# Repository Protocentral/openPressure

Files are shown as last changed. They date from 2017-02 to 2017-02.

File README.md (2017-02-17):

# Protocentral OpenPressure

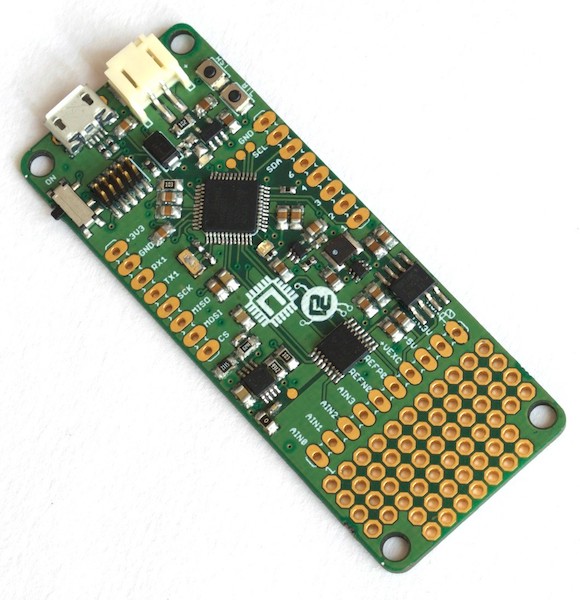
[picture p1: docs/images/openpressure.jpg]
OpenPressure


OpenPressure is a result of our work in trying to interface pressure sensors to an ADC as well as a display system based on Arduino. We found the ADS1220 to be a great chip that can directly take a 4-wire, 3-wire or a 2-wire sensor and give the digital output. 

Combine this powerful functionality with an ATSAMD21 micro-controller and you've got your very own Arduino-compatible pressure and temperature sensor interface system.

Features
--------
* TI ADS1220 24-bit ADC
* 4-wire sensor can be interfaced directly to the inputs
* On-board 5V band-gap voltage reference
* ATSAMD21 microcontroller loaded with Arduino M0/Zero bootloader
* Programmable with the Arduino IDE
* USB CDC Interface for data transfer
* "Cap" compatibility to add Bluetooth/WiFi/SD Card interfaces
* On-board 3.7V Li-Poly battery with charger
* On-board Boost DC/DC converter 

Repository Contents
-------------------
* **/hardware** - All Eagle design files (.brd, .sch)
* **/software** - Arduino libraries and example code
* **/docs** - Additional Documentation

Board Overview
--------------
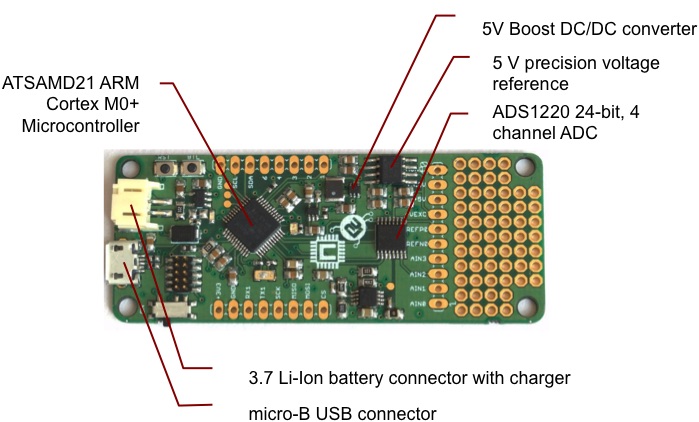
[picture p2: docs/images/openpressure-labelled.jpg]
labelled


How to setup Arduino support for openPressure
---------------------------------------------------
OpenPressure is powered by the Arduino Zero board support file.The first thing you will need to do is to download the latest release of the Arduino IDE. You will need to be using version 1.6.4 or higher. 

If you want to program your Zero while offline you need to install the Arduino Desktop IDE and add the Atmel SAMD Core to it. This simple procedure is done selecting Tools menu, then Boards and last Boards Manager, as documented in the Arduino Boards Manager page. 

* Select Tools > Board > Board Manager
* You should find Arduino SAMD(32-bit ARM cortex-M0+) boards listed in the Board Manager window.

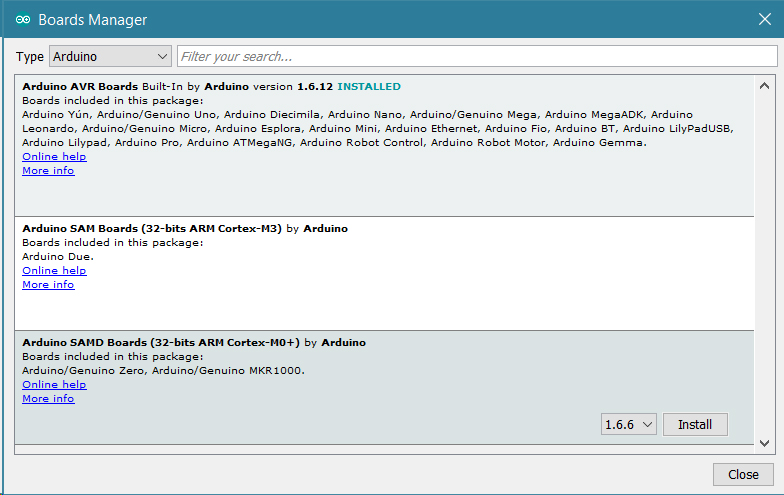
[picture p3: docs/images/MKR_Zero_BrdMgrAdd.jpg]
board_manager
 
 
* Click the “Install” button on the chosen category.The download process will begin and install the toolchain for SAMD microcontrollers.
* Restart Arduino and look under Tools > Boards and you should see the addition of the Arduino boards in your board list.
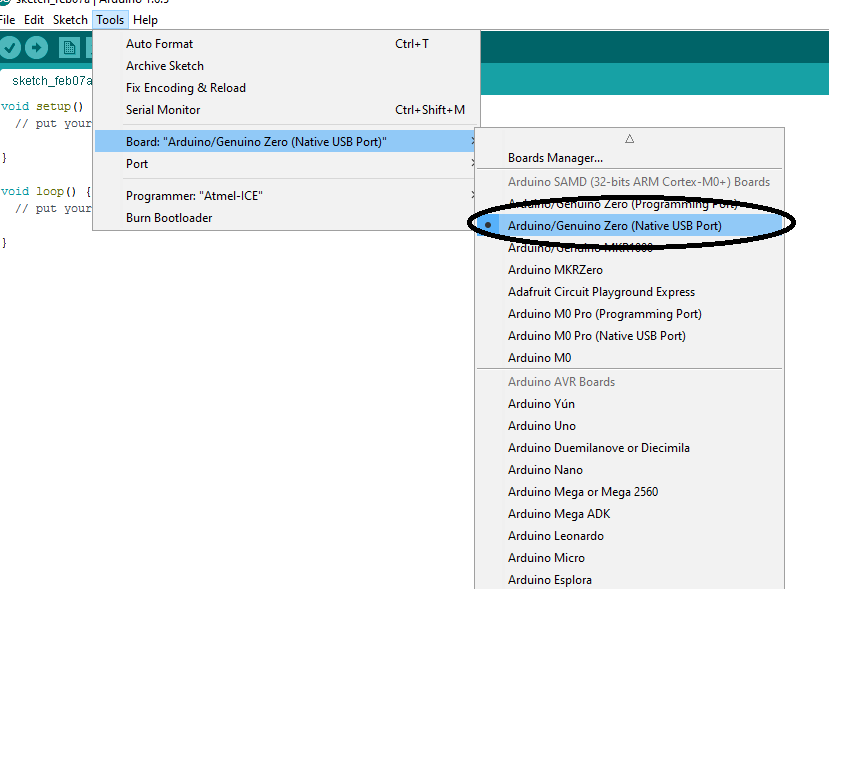
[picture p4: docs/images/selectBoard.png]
board


Setup Arduino Sketch
--------------------
We have provided a few Arduino sketch examples . They are designed to work right away with no changes. To make the examples work with your board, you simply need to upload the code to your board.

License Information
-------------------
This product is open source!

Please use, reuse, and modify these files as you see fit. Please maintain attribution to Protocentral and release anything derivative under the same license.

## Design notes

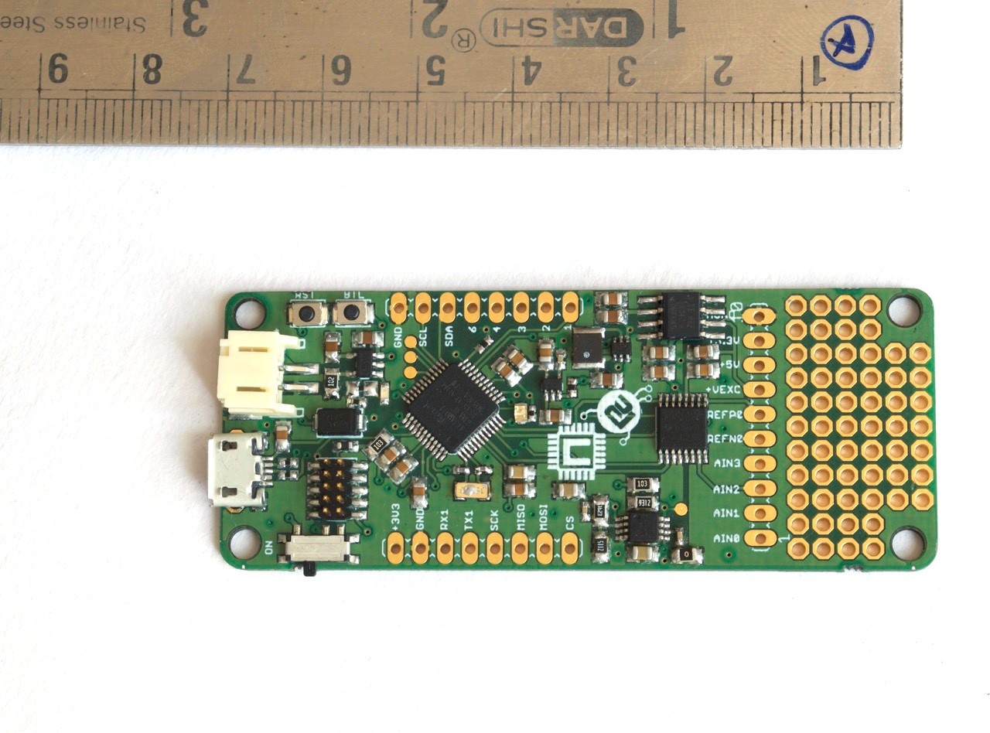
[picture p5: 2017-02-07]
docs/images/boardSize.jpg

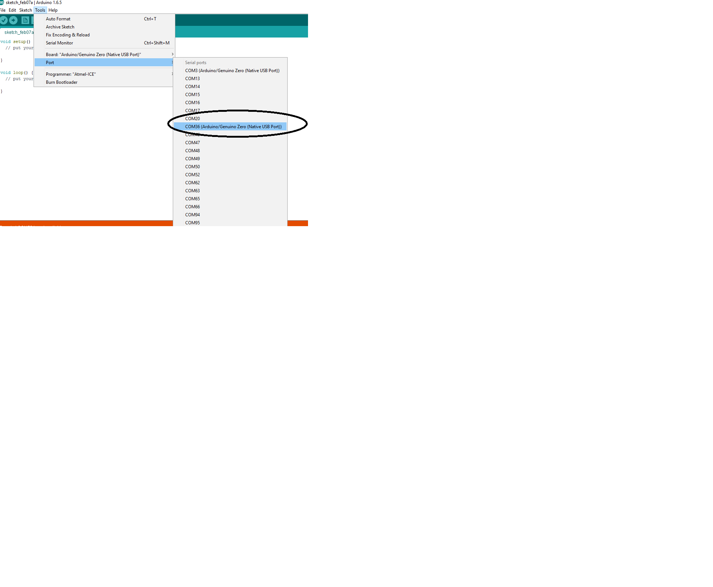
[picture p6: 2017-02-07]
docs/images/port.png

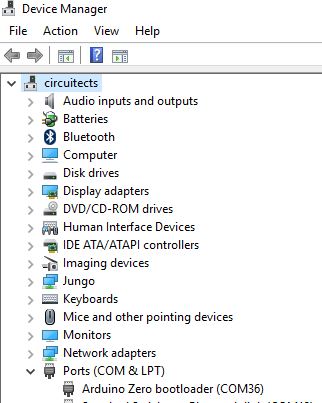
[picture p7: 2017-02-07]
docs/images/deviceManager.JPG

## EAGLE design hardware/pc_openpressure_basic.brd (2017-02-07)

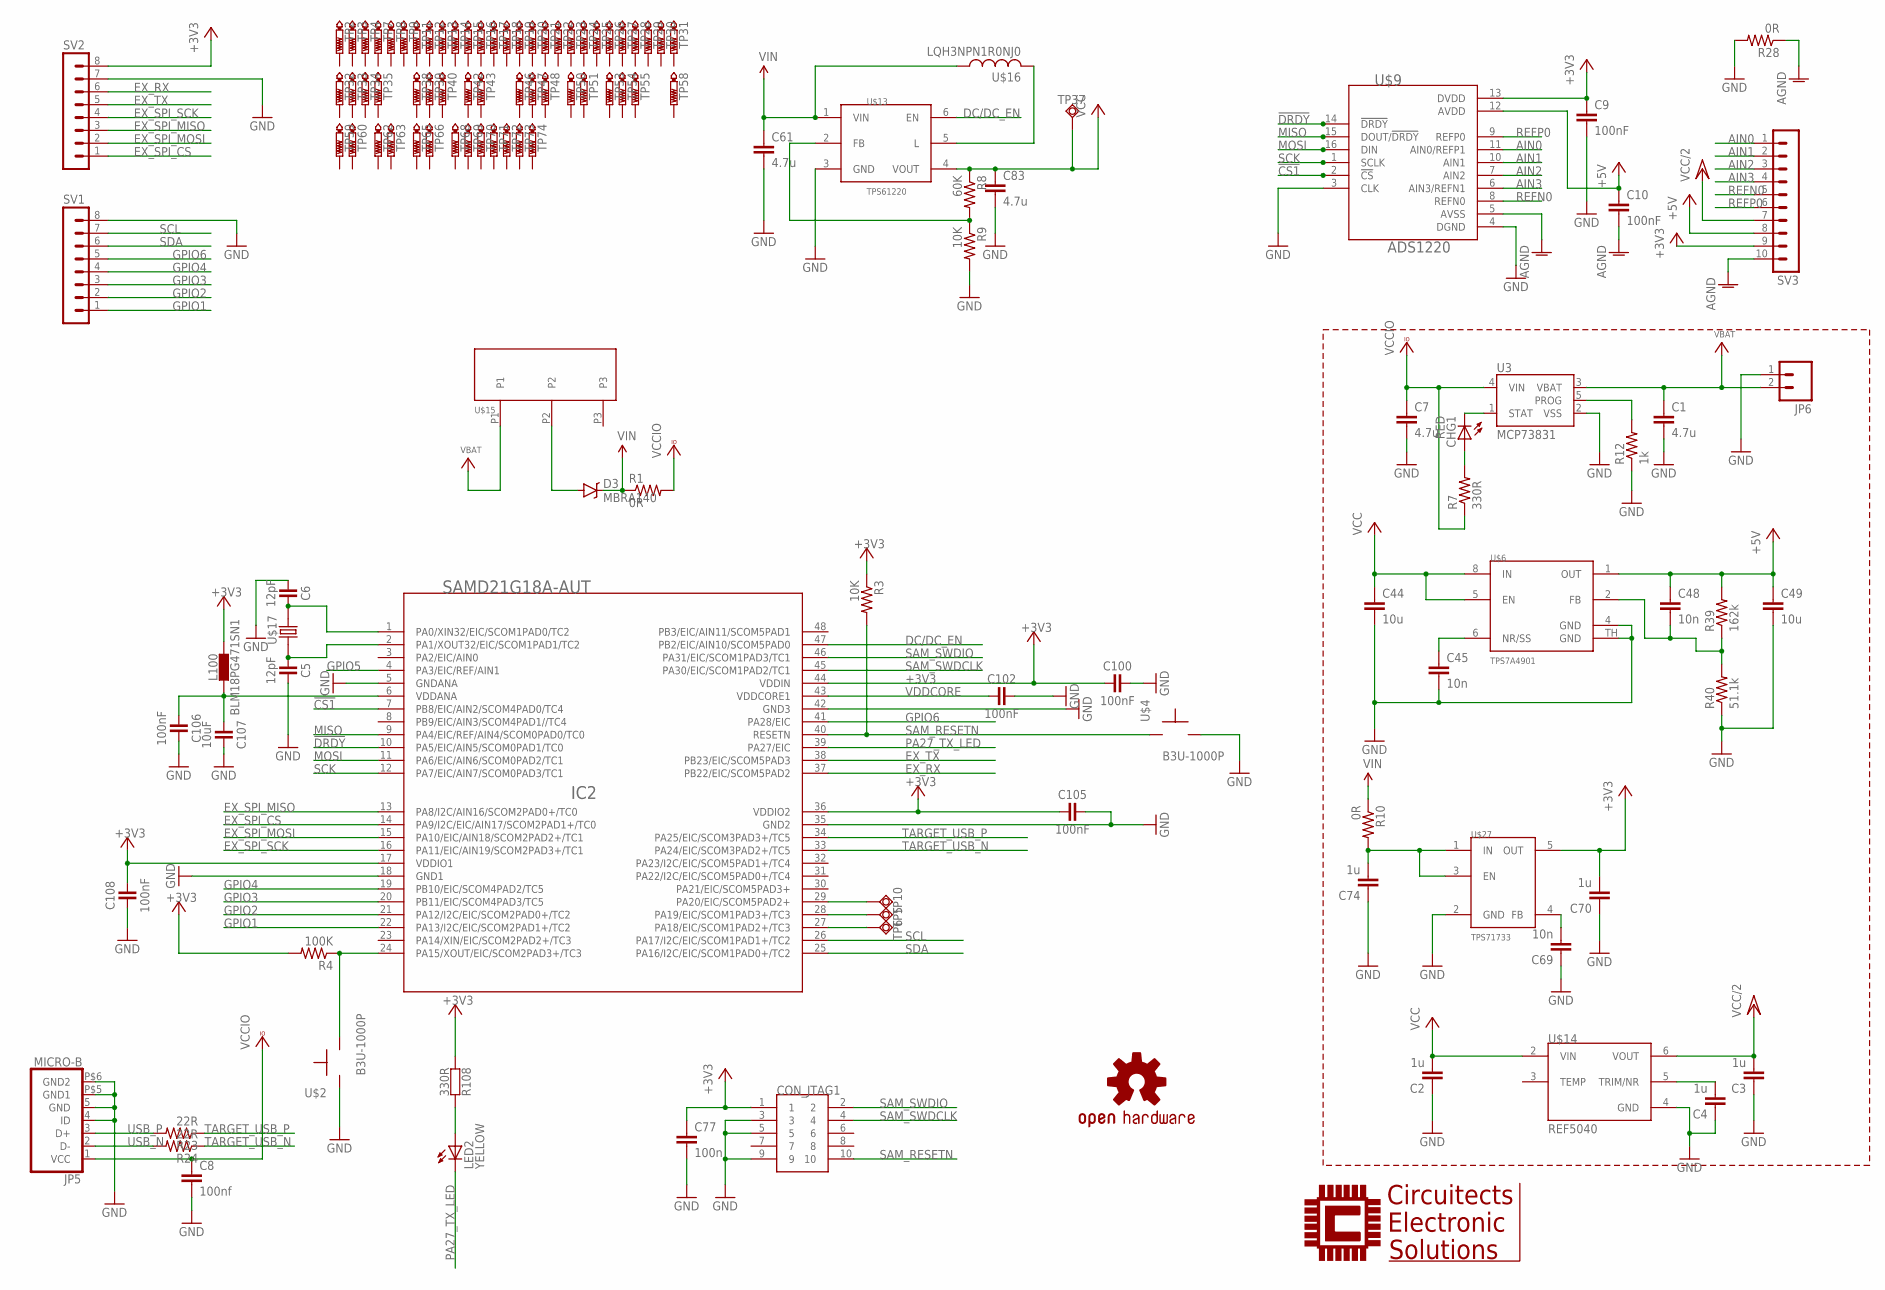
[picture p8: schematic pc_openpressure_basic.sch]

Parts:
C1, C7, C61, C83: 4.7u; C0805
C2, C3, C4, C70, C74: 1u; C0805
C5, C6: 12pF; C0402
C8: 100nf; C0805
C9, C10, C100, C102, C105, C106, C108: 100nF; C0805
C44, C49: 10u; C0805
C45, C48, C69: 10n; C0402
C77: 100n; C0805
C107: 10uF; C0805
CHG1: RED; CHIPLED_0603
CON_JTAG1: HDR-SMT-50MIL/5X2
D3: MBRA140; SMA-DIODE
IC2: SAMD21G18A-AUT; TQFP48
JP5: MICRO-B
JP6: M02-JST-2MM-SMT; JST-2-SMD
L100: BLM18PG471SN1; C0603
LED2: YELLOW; CHIPLED_0603
R1, R10: 0R; R0402
R3, R9: 10K; R0805
R4: 100K; R0402
R7: 330R; R0805
R8: 60K; R0805
R12: 1k; R0805
R23, R24: 22R; R0402
R28: 0R; R0805
R39: 162k; R0805
R40: 51.1k; R0805
R108: 330R; C0402
SV1, SV2: MA08-1
SV3: MA10-1
TP2, TP3, TP4, TP7, TP8, TP9, TP11, TP12, TP13, TP14, TP15, TP16, TP17, TP18, TP19, TP20, TP21, TP22, TP23, TP24, TP25, TP26, TP27, TP28, TP29, TP30, TP31, TP32, TP33, TP34, TP35, TP38, TP39, TP40, TP42, TP43, TP46, TP47, TP48, TP50, TP51, TP53, TP54, TP55, TP58, TP59, TP60, TP62, TP63, TP65, TP66, TP68, TP69, TP70, TP71, TP72, TP73, TP74: PTR1PAD1-13; P1-13
TP5, TP6, TP10, TP37: TPSQB1,27; B1,27
U3: MCP73831; SOT23-5
U$2, U$4: B3U-1000P
U$6: TPS7A4901; S-PDSO-G08
U$7: CES-LOGO; CES-LOGO-SMALL
U$8: PROTY-LOGO; LOGO-PROTY
U$9: ADS1220; TSSOP-16
U$13: TPS61220; SC-70-6
U$14: REF5040; SO-08M
U$15: PCM12SMTR
U$16: LQH3NPN1R0NJ0; LQH3NP
U$17: ECS-X-34B; ECX-31B
U$18: PROTY_LOGO_WITH_TEXT; PROTY_WITH_TEXT
U$19: OSHW-LOGOM; OSHW-LOGO-M
U$27: TPS71733; SC70-5

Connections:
!CS1: IC2.7 (PB8/EIC/AIN2/SCOM4PAD0/TC4), U$9.2 (!CS)
!DRDY: IC2.10 (PA5/EIC/AIN5/SCOM0PAD1/TC0), U$9.14 (!DRDY)
+3V3: C9.1, C70.2, C77.1, C100.1, C105.1, C108.2, CON_JTAG1.1, IC2.17 (VDDIO1), IC2.36 (VDDIO2), IC2.44 (VDDIN), L100.2, R3.1, R4.2, R108.1, SV2.8, SV3.9, U$9.13 (DVDD), U$27.5 (OUT)
+5V: C10.1, C48.1, C49.1, R39.2, SV3.8, U$6.1 (OUT), U$9.12 (AVDD)
AGND: C10.2, R28.1, SV3.10, U$9.5 (AVSS)
AIN0: SV3.1, U$9.11 (AIN0/REFP1)
AIN1: SV3.2, U$9.10 (AIN1)
AIN2: SV3.3, U$9.7 (AIN2)
AIN3: SV3.4, U$9.6 (AIN3/REFN1)
DC/DC_EN: IC2.47 (PB2/EIC/AIN10/SCOM5PAD0), U$13.6 (EN)
EX_RX: IC2.37 (PB22/EIC/SCOM5PAD2), SV2.6
EX_SPI_CS: IC2.14 (PA9/I2C/EIC/AIN17/SCOM2PAD1+/TC0), SV2.1
EX_SPI_MISO: IC2.13 (PA8/I2C/AIN16/SCOM2PAD0+/TC0), SV2.3
EX_SPI_MOSI: IC2.15 (PA10/EIC/AIN18/SCOM2PAD2+/TC1), SV2.2
EX_SPI_SCK: IC2.16 (PA11/EIC/AIN19/SCOM2PAD3+/TC1), SV2.4
EX_TX: IC2.38 (PB23/EIC/SCOM5PAD3), SV2.5
GND: C1.2, C2.1, C3.1, C4.1, C5.2, C6.1, C7.2, C8.2, C9.2, C44.2, C45.2, C49.2, C61.2, C69.1, C70.1, C74.1, C77.2, C83.2, C100.2, C102.2, C105.2, C106.2, C107.2, C108.1, CON_JTAG1.3, CON_JTAG1.5, CON_JTAG1.9, IC2.5 (GNDANA), IC2.18 (GND1), IC2.35 (GND2), IC2.42 (GND3), JP5.4 (ID), JP5.5 (GND), JP5.P$5 (GND1), JP5.P$6 (GND2), JP6.1, R9.2, R12.1, R28.2, R40.1, SV1.8, SV2.7, U3.2 (VSS), U$2.P$1, U$4.P$2, U$6.4 (GND), U$6.TH (GND), U$9.3 (CLK), U$9.4 (DGND), U$13.3 (GND), U$14.4 (GND), U$27.2 (GND)
GPIO1: IC2.22 (PA13/I2C/EIC/SCOM2PAD1+/TC2), SV1.1
GPIO2: IC2.21 (PA12/I2C/EIC/SCOM2PAD0+/TC2), SV1.2
GPIO3: IC2.20 (PB11/EIC/SCOM4PAD3/TC5), SV1.3
GPIO4: IC2.19 (PB10/EIC/SCOM4PAD2/TC5), SV1.4
GPIO5: IC2.4 (PA3/EIC/REF/AIN1)
GPIO6: IC2.41 (PA28/EIC), SV1.5
MISO: IC2.9 (PA4/EIC/REF/AIN4/SCOM0PAD0/TC0), U$9.15 (DOUT/!DRDY)
MOSI: IC2.11 (PA6/EIC/AIN6/SCOM0PAD2/TC1), U$9.16 (DIN)
unnamed: C6.2, IC2.1 (PA0/XIN32/EIC/SCOM1PAD0/TC2), U$17.P$2 (2)
unnamed: C74.2, R10.2, U$27.1 (IN), U$27.3 (EN)
unnamed: D3.A, U$15.P2
unnamed: R8.2, R9.1, U$13.2 (FB)
unnamed: IC2.24 (PA15/XOUT/EIC/SCOM2PAD3+/TC3), R4.1, U$2.P$2
unnamed: C5.1, IC2.2 (PA1/XOUT32/EIC/SCOM1PAD1/TC2), U$17.P$1 (1)
unnamed: C106.1, C107.1, IC2.6 (VDDANA), L100.1
unnamed: IC2.27 (PA18/EIC/SCOM1PAD2+/TC3), TP6.TP
unnamed: CHG1.C, U3.1 (STAT)
unnamed: CHG1.A, R7.2
unnamed: C45.1, U$6.6 (NR/SS)
unnamed: IC2.28 (PA19/EIC/SCOM1PAD3+/TC3), TP5.TP
unnamed: IC2.29 (PA20/EIC/SCOM5PAD2+), TP10.TP
unnamed: R12.2, U3.5 (PROG)
unnamed: LED2.A, R108.2
unnamed: C48.2, R39.1, R40.2, U$6.2 (FB)
unnamed: C4.2, U$14.5 (TRIM/NR)
unnamed: U$13.5 (L), U$16.P$2 (2)
unnamed: C69.2, U$27.4 (FB)
PA27_TX_LED: IC2.39 (PA27/EIC), LED2.C
REFN0: SV3.5, U$9.8 (REFN0)
REFP0: SV3.6, U$9.9 (REFP0)
SAM_RESETN: CON_JTAG1.10, IC2.40 (RESETN), R3.2, U$4.P$1
SAM_SWDCLK: CON_JTAG1.4, IC2.45 (PA30/EIC/SCOM1PAD2/TC1)
SAM_SWDIO: CON_JTAG1.2, IC2.46 (PA31/EIC/SCOM1PAD3/TC1)
SCK: IC2.12 (PA7/EIC/AIN7/SCOM0PAD3/TC1), U$9.1 (SCLK)
SCL: IC2.26 (PA17/I2C/EIC/SCOM1PAD1+/TC2), SV1.7
SDA: IC2.25 (PA16/I2C/EIC/SCOM1PAD0+/TC2), SV1.6
TARGET_USB_N: IC2.33 (PA24/EIC/SCOM3PAD2+/TC5), R24.1
TARGET_USB_P: IC2.34 (PA25/EIC/SCOM3PAD3+/TC5), R23.1
USB_N: JP5.2 (D-), R24.2
USB_P: JP5.3 (D+), R23.2
VBAT: C1.1, JP6.2, U3.3 (VBAT), U$15.P1
VCC: C2.2, C44.1, C83.1, R8.1, TP37.TP, U$6.5 (EN), U$6.8 (IN), U$13.4 (VOUT), U$14.2 (VIN)
VCC/2: C3.2, SV3.7, U$14.6 (VOUT)
VCCIO: C7.1, C8.1, JP5.1 (VCC), R1.2, R7.1, U3.4 (VIN)
VDDCORE: C102.1, IC2.43 (VDDCORE1)
VIN: C61.1, D3.C, R1.1, R10.1, U$13.1 (VIN), U$16.P$1 (1)

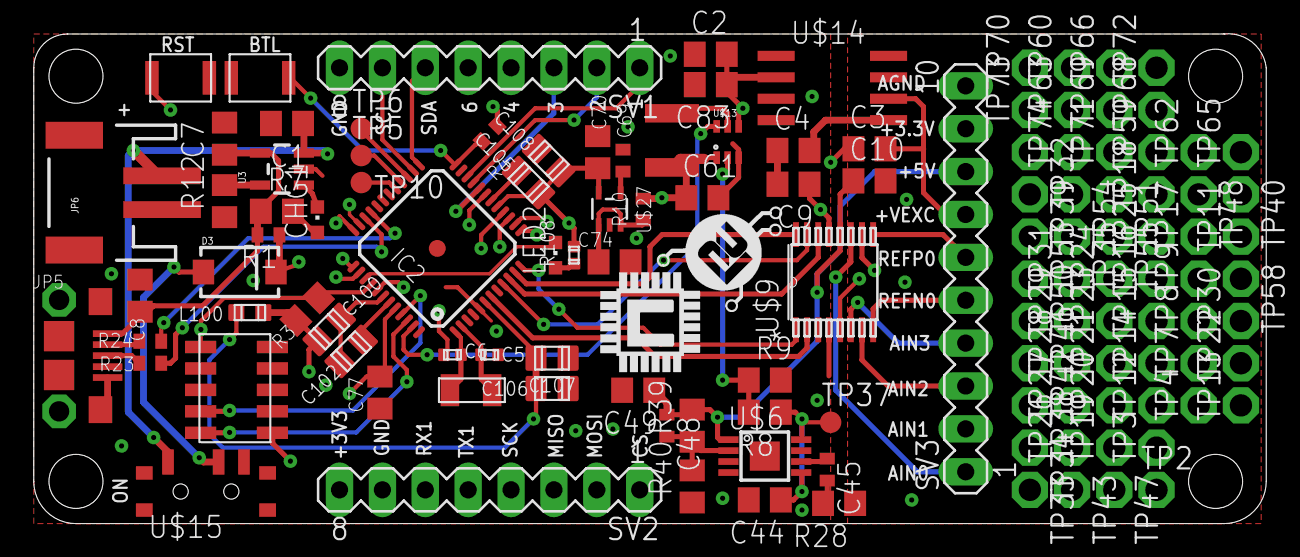
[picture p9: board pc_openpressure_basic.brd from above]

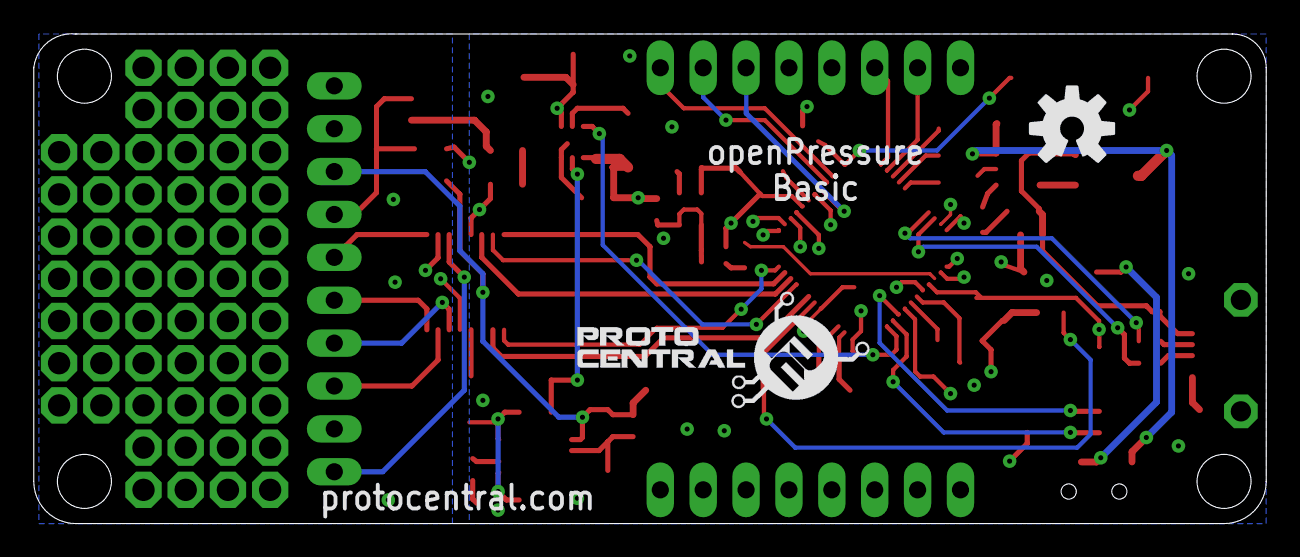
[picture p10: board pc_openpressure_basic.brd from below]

Board: 4 copper layers, 73.0 x 29.0 mm, 128 parts (2 on the bottom side), 62 nets.

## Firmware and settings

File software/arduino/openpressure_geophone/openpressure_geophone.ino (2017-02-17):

 /* +------------+------------------+--------+-----------------+--------------------------------------------------------------------------------------------------------
 * + Pin number +  ZERO Board pin  |  PIN   | Label/Name      | Comments (* is for default peripheral in use)
 * +------------+------------------+--------+-----------------+--------------------------------------------------------------------------------------------------------
 * |            | Digital Low      |        |                 |
 * +------------+------------------+--------+-----------------+--------------------------------------------------------------------------------------------------------
 * | 0          | 0 -> RX          |  PA11  |                 | EIC/EXTINT[11] ADC/AIN[19]           PTC/X[3] *SERCOM0/PAD[3]  SERCOM2/PAD[3]  TCC0/WO[3]  TCC1/WO[1]
 * | 1          | 1 <- TX          |  PA10  |                 | EIC/EXTINT[10] ADC/AIN[18]           PTC/X[2] *SERCOM0/PAD[2]                  TCC0/WO[2]  TCC1/WO[0]
 * | 2          | 2                |  PA14  |                 | EIC/EXTINT[14]                                 SERCOM2/PAD[2]  SERCOM4/PAD[2]  TC3/WO[0]   TCC0/WO[4]
 * | 3          | ~3               |  PA09  |                 | EIC/EXTINT[9]  ADC/AIN[17]           PTC/X[1]  SERCOM0/PAD[1]  SERCOM2/PAD[1] *TCC0/WO[1]  TCC1/WO[3]
 * | 4          | ~4               |  PA08  |                 | EIC/NMI        ADC/AIN[16]           PTC/X[0]  SERCOM0/PAD[0]  SERCOM2/PAD[0] *TCC0/WO[0]  TCC1/WO[2]
 * | 5          | ~5               |  PA15  |                 | EIC/EXTINT[15]                                 SERCOM2/PAD[3]  SERCOM4/PAD[3] *TC3/WO[1]   TCC0/WO[5]
 * | 6          | ~6               |  PA20  |                 | EIC/EXTINT[4]                        PTC/X[8]  SERCOM5/PAD[2]  SERCOM3/PAD[2]             *TCC0/WO[6]
 * | 7          | 7                |  PA21  |                 | EIC/EXTINT[5]                        PTC/X[9]  SERCOM5/PAD[3]  SERCOM3/PAD[3]              TCC0/WO[7]
 * +------------+------------------+--------+-----------------+--------------------------------------------------------------------------------------------------------
 * |            | Digital High     |        |                 |
 * +------------+------------------+--------+-----------------+--------------------------------------------------------------------------------------------------------
 * | 8          | ~8               |  PA06  |                 | EIC/EXTINT[6]  ADC/AIN[6]  AC/AIN[2] PTC/Y[4]  SERCOM0/PAD[2]                 *TCC1/WO[0]
 * | 9          | ~9               |  PA07  |                 | EIC/EXTINT[7]  ADC/AIN[7]  AC/AIN[3] PTC/Y[5]  SERCOM0/PAD[3]                 *TCC1/WO[1]
 * | 10         | ~10              |  PA18  |                 | EIC/EXTINT[2]                        PTC/X[6] +SERCOM1/PAD[2]  SERCOM3/PAD[2] *TC3/WO[0]    TCC0/WO[2]
 * | 11         | ~11              |  PA16  |                 | EIC/EXTINT[0]                        PTC/X[4] +SERCOM1/PAD[0]  SERCOM3/PAD[0] *TCC2/WO[0]   TCC0/WO[6]
 * | 12         | ~12              |  PA19  |                 | EIC/EXTINT[3]                        PTC/X[7] +SERCOM1/PAD[3]  SERCOM3/PAD[3]  TC3/WO[1]   *TCC0/WO[3]
 * | 13         | ~13              |  PA17  | LED             | EIC/EXTINT[1]                        PTC/X[5] +SERCOM1/PAD[1]  SERCOM3/PAD[1] *TCC2/WO[1]   TCC0/WO[7]
 * +------------+------------------+--------+-----------------+--------------------------------------------------------------------------------------------------------
 * |            | Analog Connector |        |                 |
 * +------------+------------------+--------+-----------------+--------------------------------------------------------------------------------------------------------
 * | 14         | A0               |  PA02  | A0              | EIC/EXTINT[2] *ADC/AIN[0]  DAC/VOUT  PTC/Y[0]
 * | 15         | A1               |  PB08  | A1              | EIC/EXTINT[8] *ADC/AIN[2]            PTC/Y[14] SERCOM4/PAD[0]                  TC4/WO[0]
 * | 16         | A2               |  PB09  | A2              | EIC/EXTINT[9] *ADC/AIN[3]            PTC/Y[15] SERCOM4/PAD[1]                  TC4/WO[1]
 * | 17         | A3               |  PA04  | A3              | EIC/EXTINT[4] *ADC/AIN[4]  AC/AIN[0] PTC/Y[2]  SERCOM0/PAD[0]                  TCC0/WO[0]
 * | 18         | A4               |  PA05  | A4              | EIC/EXTINT[5] *ADC/AIN[5]  AC/AIN[1] PTC/Y[5]  SERCOM0/PAD[1]                  TCC0/WO[1]
 * | 19         | A5               |  PB02  | A5              | EIC/EXTINT[2] *ADC/AIN[10]           PTC/Y[8]  SERCOM5/PAD[0]
 * +------------+------------------+--------+-----------------+--------------------------------------------------------------------------------------------------------
 * |            | Wire             |        |                 |
 * +------------+------------------+--------+-----------------+--------------------------------------------------------------------------------------------------------
 * | 20         | SDA              |  PA22  | SDA             | EIC/EXTINT[6]                        PTC/X[10] *SERCOM3/PAD[0] SERCOM5/PAD[0] TC4/WO[0] TCC0/WO[4]
 * | 21         | SCL              |  PA23  | SCL             | EIC/EXTINT[7]                        PTC/X[11] *SERCOM3/PAD[1] SERCOM5/PAD[1] TC4/WO[1] TCC0/WO[5]
 * +------------+------------------+--------+-----------------+--------------------------------------------------------------------------------------------------------
 * |            |SPI (Legacy ICSP) |        |                 |
 * +------------+------------------+--------+-----------------+--------------------------------------------------------------------------------------------------------
 * | 22         | 1                |  PA12  | MISO            | EIC/EXTINT[12] SERCOM2/PAD[0] *SERCOM4/PAD[0] TCC2/WO[0] TCC0/WO[6]
 * |            | 2                |        | 5V0             |
 * | 23         | 4                |  PB10  | MOSI            | EIC/EXTINT[10]                *SERCOM4/PAD[2] TC5/WO[0]  TCC0/WO[4]
 * | 24         | 3                |  PB11  | SCK             | EIC/EXTINT[11]                *SERCOM4/PAD[3] TC5/WO[1]  TCC0/WO[5]
 * |            | 5                |        | RESET           |
 * |            | 6                |        | GND             |
 * +------------+------------------+--------+-----------------+--------------------------------------------------------------------------------------------------------
 * |            | LEDs             |        |                 |
 * +------------+------------------+--------+-----------------+--------------------------------------------------------------------------------------------------------
 * | 25         |                  |  PB03  | RX              |
 * | 26         |                  |  PA27  | TX              |
 * +------------+------------------+--------+-----------------+--------------------------------------------------------------------------------------------------------
 * |            | USB              |        |                 |
 * +------------+------------------+--------+-----------------+--------------------------------------------------------------------------------------------------------
 * | 27         |                  |  PA28  | USB_HOST_ENABLE | EIC/EXTINT[8]
 * | 28         |                  |  PA24  | USB_NEGATIVE    | *USB/DM
 * | 29         |                  |  PA25  | USB_POSITIVE    | *USB/DP
 * +------------+------------------+--------+-----------------+--------------------------------------------------------------------------------------------------------
 * |            | EDBG             |        |                 |
 * +------------+------------------+--------+-----------------+--------------------------------------------------------------------------------------------------------
 * | 30         |                  |  PB22  | EDBG_UART TX    | *SERCOM5/PAD[2]
 * | 31         |                  |  PB23  | EDBG_UART RX    | *SERCOM5/PAD[3]
 * +------------+------------------+--------+-----------------+--------------------------------------------------------------------------------------------------------
 * | 32         |                  |  PA22  | EDBG_SDA        | Pin 20 (SDA)
 * | 33         |                  |  PA23  | EDBG_SCL        | Pin 21 (SCL)
 * +------------+------------------+--------+-----------------+--------------------------------------------------------------------------------------------------------
 * | 34         |                  |  PA19  | EDBG_MISO       | EIC/EXTINT[3] *SERCOM1/PAD[3] SERCOM3/PAD[3] TC3/WO[1]  TCC0/WO[3]
 * | 35         |                  |  PA16  | EDBG_MOSI       | EIC/EXTINT[0] *SERCOM1/PAD[0] SERCOM3/PAD[0] TCC2/WO[0] TCC0/WO[6]
 * | 36         |                  |  PA18  | EDBG_SS         | EIC/EXTINT[2] *SERCOM1/PAD[2] SERCOM3/PAD[2] TC3/WO[0]  TCC0/WO[2]
 * | 37         |                  |  PA17  | EDBG_SCK        | EIC/EXTINT[1] *SERCOM1/PAD[1] SERCOM3/PAD[1] TCC2/WO[1] TCC0/WO[7]
 * +------------+------------------+--------+-----------------+--------------------------------------------------------------------------------------------------------
 * | 38         | ATN              |  PA13  | EDBG_GPIO0      | EIC/EXTINT[13] SERCOM2/PAD[1] SERCOM4/PAD[1] *TCC2/WO[1] TCC0/WO[7]
 * | 39         |                  |  PA21  | EDBG_GPIO1      | Pin 7
 * | 40         |                  |  PA06  | EDBG_GPIO2      | Pin 8
 * | 41         |                  |  PA07  | EDBG_GPIO3      | Pin 9
 * +------------+------------------+--------+-----------------+--------------------------------------------------------------------------------------------------------
 * |            |                  |        |                 |
 * +------------+------------------+--------+-----------------+--------------------------------------------------------------------------------------------------------
 * |            | GND              |        |                 |
 * | 42         | AREF             |  PA03  |                 | EIC/EXTINT[3] *[ADC|DAC]/VREFA ADC/AIN[1] PTC/Y[1]
 * +------------+------------------+--------+-----------------+--------------------------------------------------------------------------------------------------------
 * |            |32.768KHz Crystal |        |                 |
 * +------------+------------------+--------+-----------------+--------------------------------------------------------------------------------------------------------
 * |            |                  |  PA00  | XIN32           | EIC/EXTINT[0] SERCOM1/PAD[0] TCC2/WO[0]
 * |            |                  |  PA01  | XOUT32          | EIC/EXTINT[1] SERCOM1/PAD[1] TCC2/WO[1]
 * +------------+------------------+--------+-----------------+--------------------------------------------------------------------------------------------------------
 */

#include <SPI.h>
#include "wiring_private.h" // pinPeripheral() function

//SPI class(MISO
SPIClass mySPI (&sercom0, 17, 9 , 8, SPI_PAD_2_SCK_3, SERCOM_RX_PAD_0);    // ads1220 17 -->PA4 9-->  8-->

//Uart class
Uart BluetoothSerial( &sercom5, 31, 30, SERCOM_RX_PAD_3, UART_TX_PAD_2) ;  //bluetooth

//Pin definition
#define CHECK_PIN 0
#define ADS1220_CS_PIN SS
#define ADS1220_DRDY_PIN A4
#define DC_DC_ENABLE A5
#define BLUETOOTH_RESET 27
#define PIN_DRDY  A4

#define SPI_MASTER_DUMMY   0xFF
#define RESET 0x06                                                    //Send the RESET command (06h) to make sure the ADS1220 is properly reset after power-up
#define START 0x08                                         //Send the START/SYNC command (08h) to start converting in continuous conversion mode
#define WREG  0x40
#define RREG  0x20
#define STOP   0x02
#define CONFIG_REG0_ADDRESS 0x00
#define CONFIG_REG1_ADDRESS 0x01
#define CONFIG_REG2_ADDRESS 0x02
#define CONFIG_REG3_ADDRESS 0x03


#define REG_CONFIG_DR_20SPS 0x00
#define REG_CONFIG_DR_45SPS 0x20
#define REG_CONFIG_DR_90SPS 0x40
#define REG_CONFIG_DR_175SPS 0x60
#define REG_CONFIG_DR_330SPS 0x80
#define REG_CONFIG_DR_600SPS 0xA0
#define REG_CONFIG_DR_1000SPS 0xC0
#define REG_CONFIG_DR_MASK 0xE0

#define DR_20SPS 20
#define DR_45SPS 45
#define DR_90SPS 90
#define DR_175SPS 175
#define DR_330SPS 330
#define DR_600SPS 600
#define DR_1000SPS 1000

#define REG_CONFIG_PGA_GAIN_1 0x00
#define REG_CONFIG_PGA_GAIN_2 0x02
#define REG_CONFIG_PGA_GAIN_4 0x04
#define REG_CONFIG_PGA_GAIN_8 0x06
#define REG_CONFIG_PGA_GAIN_16 0x08
#define REG_CONFIG_PGA_GAIN_32 0x0A
#define REG_CONFIG_PGA_GAIN_64 0x0C
#define REG_CONFIG_PGA_GAIN_128 0x0E
#define REG_CONFIG_PGA_GAIN_MASK 0x0E

#define PGA_GAIN_1 1
#define PGA_GAIN_2 2
#define PGA_GAIN_4 4
#define PGA_GAIN_8 8
#define PGA_GAIN_16 16
#define PGA_GAIN_32 32
#define PGA_GAIN_64 64
#define PGA_GAIN_128 128

uint8_t Config_Reg0;
uint8_t Config_Reg1;
uint8_t Config_Reg2;
uint8_t Config_Reg3;
int8_t NewDataAvailable;

#define PGA 1
#define VREF 2.048
#define VFSR VREF/PGA
#define FSR (((long int)1<<23)-1)

volatile byte MSB;
volatile byte data;
volatile byte LSB;
volatile long count=0;

volatile byte *SPI_RX_Buff_Ptr;

volatile char DataPacketHeader[16];


void setup() {
  SerialUSB.begin(9600);
  BluetoothSerial.begin(115200);
  
  // do this first, for Reasons
  mySPI.begin();
  pinMode(SS, OUTPUT);
  pinMode(ADS1220_DRDY_PIN,INPUT);
  pinMode(DC_DC_ENABLE , OUTPUT);
  pinMode(BLUETOOTH_RESET,OUTPUT);

  pinMode(PIN_DRDY, INPUT);
  pinMode(PIN_DRDY, INPUT_PULLUP);
  attachInterrupt(PIN_DRDY, onA4Change, FALLING);
  
  digitalWrite(DC_DC_ENABLE, HIGH);   // turn the LED on (HIGH is the voltage level)
  digitalWrite(BLUETOOTH_RESET, HIGH);
  //pinMode(CHECK_PIN,OUTPUT);
   
   pinPeripheral(17, PIO_SERCOM_ALT);
   pinPeripheral(9, PIO_SERCOM_ALT);
   pinPeripheral(8, PIO_SERCOM_ALT);
  
   mySPI.beginTransaction(SPISettings(1000000, MSBFIRST, SPI_MODE1));
   ads1220begin();
}


void onA4Change() {
 //SerialUSB.println("A4 change");
    NewDataAvailable = true;
    count++;
}


uint8_t i = 0;
void loop() {

  long int bit32;
  long int bit24;
  byte *config_reg;

  if(!(millis()%1000))
  {
     //SerialUSB.println(count); // print to check
    count = 0;
  }

  
  if(NewDataAvailable == true)
  {
   
      SPI_RX_Buff_Ptr = Read_Data();
     
      MSB = SPI_RX_Buff_Ptr[0];    
      data = SPI_RX_Buff_Ptr[1];
      LSB = SPI_RX_Buff_Ptr[2];
    
      bit24 = MSB;
      bit24 = (bit24 << 8) | data;
      bit24 = (bit24 << 8) | LSB;                                 // Converting 3 bytes to a 24 bit int
        
      bit24= ( bit24 << 8 );
      bit32 = ( bit24 >> 8 );                      // Converting 24 bit two's complement to 32 bit two's complement
      
      float Vout = (float)((bit32*VFSR*100000)/FSR);     //In  mV
      SerialUSB.println(Vout);
   
      DataPacketHeader[0] = 0x0A;  // Packet Header
      DataPacketHeader[1] = 0xFA;  // Packet Header
      DataPacketHeader[2] = 0x04;  // Data Length LSB in Bytes
      DataPacketHeader[3] = 0;     // Data Length MSB in Bytes
      DataPacketHeader[4] = 0x02;  // Packet type 0x01->command , 0x02->data
    
    
      DataPacketHeader[5] = (int)Vout;       // data LSB
      DataPacketHeader[6] = (int)Vout >> 8;  //
      DataPacketHeader[7] = (int)Vout >> 16;
      DataPacketHeader[8] = (int)Vout >> 24; //Data MSB
    
      DataPacketHeader[9] = 0x00;
      DataPacketHeader[10] = 0x0B;      // Packet footer
    
      for (i = 0; i < 11; i++)
      {
     //   SerialUSB.write(DataPacketHeader[i]); // transmit through uart line
         BluetoothSerial.write(DataPacketHeader[i]);
      }
            NewDataAvailable = false;
     
  }

}


void ads1220begin()
{
  
  SPI_Reset();                                            
  delay(100);                                                    

  digitalWrite(ADS1220_CS_PIN,LOW);

  Config_Reg0 = 0x01;  // AN1-AN0, gain=1,PGA enabled
  Config_Reg1 = 0x44;   //0x00-sinlge , 0x04-cont
  Config_Reg2 = 0x10;  //10 //55
  Config_Reg3 = 0x00;
  

  writeRegister( CONFIG_REG0_ADDRESS , Config_Reg0);
  writeRegister( CONFIG_REG1_ADDRESS , Config_Reg1);
  writeRegister( CONFIG_REG2_ADDRESS , Config_Reg2);
  writeRegister( CONFIG_REG3_ADDRESS , Config_Reg3);
  
  delay(100);
 
  Config_Reg0 = readRegister(CONFIG_REG0_ADDRESS);
  Config_Reg1 = readRegister(CONFIG_REG1_ADDRESS);
  Config_Reg2 = readRegister(CONFIG_REG2_ADDRESS);
  Config_Reg3 = readRegister(CONFIG_REG3_ADDRESS);

  SerialUSB.println("Config_Reg : ");
  SerialUSB.println(Config_Reg0,HEX);
  SerialUSB.println(Config_Reg1,HEX);
  SerialUSB.println(Config_Reg2,HEX);
  SerialUSB.println(Config_Reg3,HEX);
  SerialUSB.println(" ");
  digitalWrite(ADS1220_CS_PIN,HIGH); //release chip, signal end transfer

  SPI_Start();
  delay(10);
}




void writeRegister(uint8_t address, uint8_t value)
{
  digitalWrite(ADS1220_CS_PIN,LOW);
  delay(5);
  mySPI.transfer(WREG|(address<<2));        
  mySPI.transfer(value); 
  delay(5);
  digitalWrite(ADS1220_CS_PIN,HIGH);
}  


uint8_t readRegister(uint8_t address)
{
  uint8_t data;

  digitalWrite(ADS1220_CS_PIN,LOW);
  delay(5);
  mySPI.transfer(RREG|(address<<2));        
  data = mySPI.transfer(SPI_MASTER_DUMMY); 
  delay(5);
  digitalWrite(ADS1220_CS_PIN,HIGH);

  return data;
}  

uint8_t * Read_Data()
{
  static byte SPI_Buff[3];

 // if((digitalRead(ADS1220_DRDY_PIN)) == LOW)             //        Wait for DRDY to transition low
  {
    digitalWrite(ADS1220_CS_PIN,LOW);                         //Take CS low
  //  delayMicroseconds(10);
    for (int i = 0; i < 3; i++)
    { 
      SPI_Buff[i] = mySPI.transfer(SPI_MASTER_DUMMY);
    }
  //  delayMicroseconds(10);
    digitalWrite(ADS1220_CS_PIN,HIGH);                  //  Clear CS to high
   
  }
    
  return SPI_Buff;
}

void SPI_Reset()
{
  SPI_Command(RESET);                              
}

void SPI_Start()
{
  SPI_Command(START);
}

void SPI_Stop()
{
  SPI_Command(STOP);
}

void SPI_Command(unsigned char data_in)
{
  digitalWrite(ADS1220_CS_PIN, LOW);
  delay(2);
  digitalWrite(ADS1220_CS_PIN, HIGH);
  delay(2);
  digitalWrite(ADS1220_CS_PIN, LOW);
  delay(2);
  mySPI.transfer(data_in);
  delay(2);
  digitalWrite(ADS1220_CS_PIN, HIGH);
}

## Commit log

2017-01-19 Measures pressure based on 0-2Bar pressure, code optimization yet to do
2017-02-07 updated image
    [pc_openpressure_basic.brd, pc_openpressure_basic.sch]
2017-02-17 Updated Arduino Examples

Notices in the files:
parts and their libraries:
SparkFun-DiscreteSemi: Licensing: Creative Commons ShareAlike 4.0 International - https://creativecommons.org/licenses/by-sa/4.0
